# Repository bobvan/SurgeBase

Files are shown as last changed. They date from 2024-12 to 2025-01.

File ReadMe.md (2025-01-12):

# Overview
This is a simple project to make a blue LED appear to "surge" by
ramping the brightness.
It's made from a low-power MCU and an addressable
RGB LED ("NeoPixel").
The ramping code is CircuitPython.
The hardware is designed to fit inside a 50 mm OD hemisphere, forming
the base of a Marvel Crisis Protocol figure.
Demo Shell
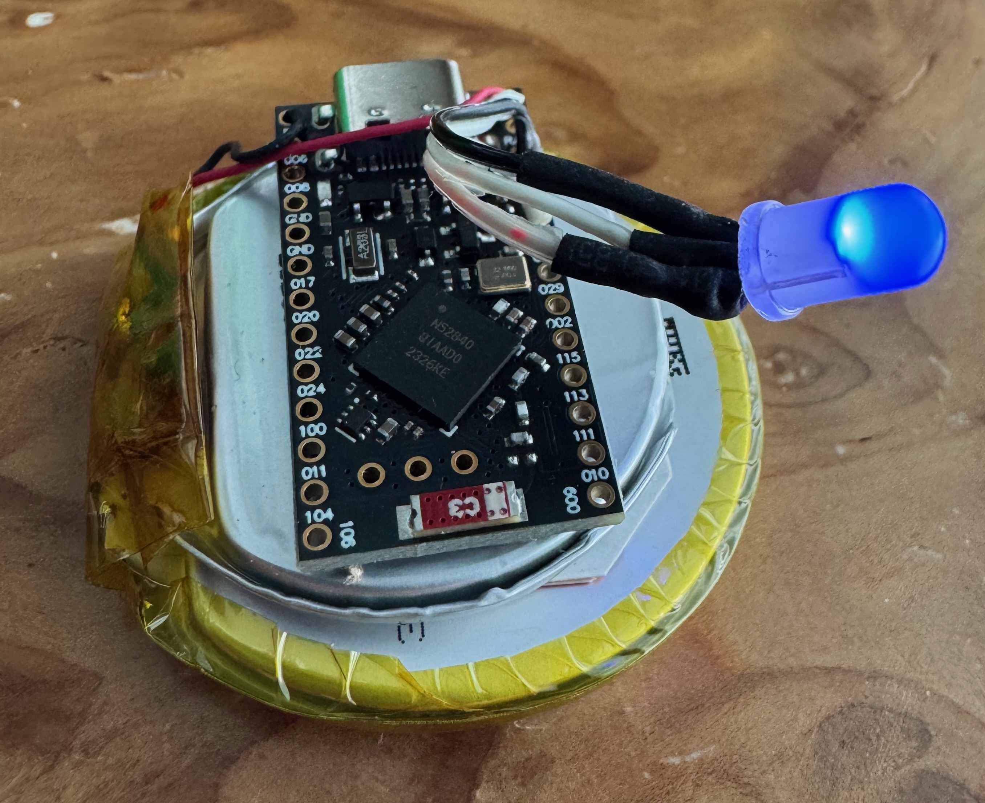
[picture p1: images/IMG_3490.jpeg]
Guts Without Shell One

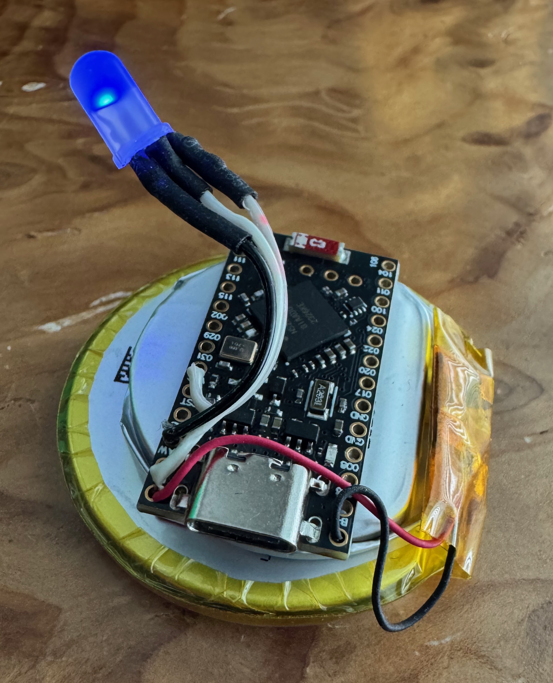
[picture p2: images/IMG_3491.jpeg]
Guts Without Shell Two


# Hardware
* NRF52840 Low Power MCU https://www.amazon.com/dp/B0DCZJKYL1
* 5 mm RGB LED with integrated controller, often called "NeoPixel" by Adafruit, or goes by part number WS2811 or WS2812: https://www.amazon.com/gp/product/B071FND4WK/
* Grepow Round LiPo Battery 1050 mAh, 45 mm: https://www.digikey.com/en/products/detail/grepow-inc/GRP604543-1C-3-85V-1050mAh/25603150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
  * This version doesn't have the protection circucit
  * It was the only one of this capacity and size when I ordered
  * I just soldered it on to the protection circuit of the cell below
* Grepow Round LiPo Battery 545 mAh, 35 mm: https://www.digikey.com/en/products/detail/grepow-inc/GRP483535-3-8V-545MAH/13681485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

# Software
* Circuit Python 9.2.1. Binary in `Downloads`.
* NeoPixel Driver Libary for above, extracted from `adafruit-circuitpython-bundle-9.x-mpy-20241224`. Binary in `Downloads`.

# Software Installation
* When you plug in the NRF52840 fresh from the factory, it will mount the MCU flash for running firmware as a volume named `NICENANO`.
* Copy the CircuitPython `.UF2` file from `Downloads` to that volume to install the firmware on the flash of the MCU.
```
cp Downloads/adafruit-circuitpython-supermini_nrf52840-en_US-9.2.1.uf2 /Volumes/NICENANO
```
* Successful installation of CircuitPython will cause the MCU to reboot, so you'll get a warning message that the `NICENANO` volume was not ejected before disconnecting. This is expected.
* When CircuitPython boots, it will mount the flash used for running CircuitPython code as a volume named `CIRCUITPY`.
* Copy the NeoPixel library from `Downloads` into the `/lib/` directory of that volume.
```
cp Downloads/neopixel.mpy /Volumes/CIRCUITPY/lib/
```
* Finally copy the SurgeBase code to the `CIRCUITPY` volume.
```
cp fw/code.py /Volumes/CIRCUITPY
```
* Eject the `CIRCUITPY` volume.
* Plug out the MCU and then plug it back in. The MCU should reboot and start running SurgeBase if you haven't attached a battery.

# Construction
* Spread four leads of LED.
* Cut off the one on the flat side. (It would daisy chain to the next LED in sequence, but we're only using one.)
* Cut the remaining three legs where they have a crimp mark.
* Prepare three stranded wires about 45 mm to connect the LED to the MCU.
* Prepare three pieces of heat shrink tubing about 8 mm.
* Strip about 5 mm of insulation.
* If PVC insulation, be ready for it to shrink back several mm when soldered.
* If ribbon cable, split LED end back so when heat shrink is placed over it, at least 5 mm of insulation is exposed.
* Place heat shrink tubing over wires.
* Tin ends.
* Solder LED to tinned wires.
* Slide tubing over solder joints and heat to shrink.
* Solder wires to MCU following table below.

| NeoPixel Pin | MCU Pin |
|---|---|
| `Data In` | `031` |
| `+5 V` | `B+` |
| `Ground` | `GND` |
| `Data Out` | N/C |
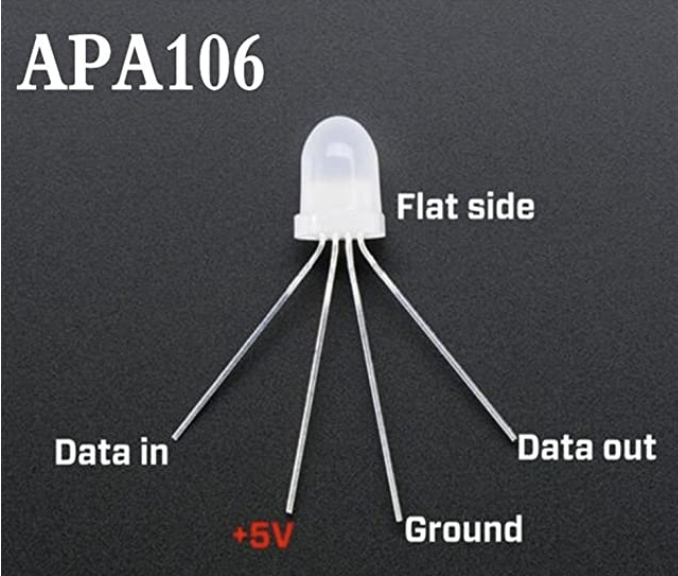
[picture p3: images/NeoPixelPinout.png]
NeoPixel Pinout

* If 1050 mAh batter doesn't have a BMS or Protection Circuit Module (PCM) but the 545 mAh battery does, then kludge them to both use the same BMS:
  * Charge both batteries fully.
  * Remove tape on BMS.
  * Tin cell tabs on both batteries.
  * Solder cells in parallel.
  * Insulate with Kapton tape.
* Solder battery to `B-` and `B+` pins of MCU.
* Use foam mounting tape to secure batteries and PCB.
* Use putty to stick assembly to shell.

# Troubleshooting
* If light blinks, MCU may by hung from power glitches while soldering the battery. Try briefly shorting the MCU `RST` pin to `GND` to reset it.
* For debugging or development, connect MCU USB to a host and run a terminal emulator on the USB serial port at 115200 baud.
```
screen /dev/cu.usbmodem11401
```
* You may have to hit `Control-C` to interrupt Circuit Python to get a REPL prompt if it's busy running your code.

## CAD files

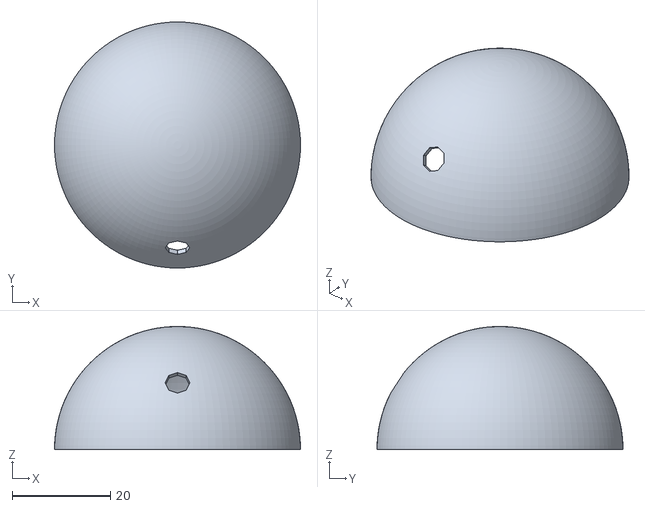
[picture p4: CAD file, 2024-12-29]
shell/shell.stl
50.0 x 50.0 x 25.0

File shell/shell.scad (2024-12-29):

// Parameters for the hemisphere
radius = 25;  // Radius of the hemisphere

module hemisphere(radius) {
    difference() {
        // Full sphere
        sphere(r = radius, $fn = 100);

        // Remove the lower half
        translate([0, 0, -radius/2])
            cube([radius * 2, radius * 2, radius], center = true);
    }
}

difference() {
    hemisphere(radius);
    hemisphere(radius-1);
    rotate([57, 0, 0]) {
         cylinder(radius*2, 2.5, 2.5);
    }
}

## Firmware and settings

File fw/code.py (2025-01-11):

# flake8: noqa: E221
#
# Ramp the brightness of a NeoPixel blue LED up and down logarithmically, resulting
# a linear ramp in perceived brightness.
# Should result in a surging effect.

import board
import neopixel
import math
import time

# Configuration Constants
rampSteps  = 40  # Number of steps as ramp rises and falls
rampStepMs = 30  # Time in milliseconds between steps
neoPin     = board.P0_31   # Pin for NeoPixel

# Manifest Constants
ledMax = 255    # Max brightness value for LED

# Derived Constants
brightStep = 1/rampSteps    # Size of steps in linear ramp

# Ten percent fudge factor to account for accumulating floating point errors
brightFudge = brightStep/10

np = neopixel.NeoPixel(neoPin, 1)

ramp = []       # Ramp of calculated brightness values

# Converting a linear brightness of 0 to a logarithmic brightness takes exp(0),
# which is 1, so the LED never goes off unless the first value is forced to 0.
ramp.append(0)

# Increasing brightness ramp
linBright = brightStep
while linBright <= 1+brightFudge:
    logBright = int(math.exp(linBright * math.log(ledMax)))
    ramp.append(logBright)
    linBright += brightStep

# Decreasing brightness ramp
linBright = 1
while linBright >= brightStep+brightFudge:
    linBright -= brightStep
    logBright = int(math.exp(linBright * math.log(ledMax)))
    ramp.append(logBright)

assert len(ramp) == 2*rampSteps, \
       "Expecting ramp length of " + str(2*rampSteps) + \
       ", got " + str(len(ramp))
print(ramp)

while True:
    for brightness in ramp:
        np[0] = (0, 0, brightness) # Set NeoPixel blue LED to calculated brightness
        np.write()
        time.sleep(rampStepMs/1000)

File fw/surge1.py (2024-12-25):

# Surging brightness effect using PWM on an individual LED.
from machine import Pin, PWM
from time import sleep
import math

# Initialize PWM on the LED pin
led_pin = Pin(2)  # Replace with your LED pin number
led_pwm = PWM(led_pin)
led_pwm.freq(1000)  # Set PWM frequency to 1kHz

# Function to calculate duty cycle based on human perception
def perceived_brightness(level, max_duty):
    """
    Maps a level (0 to 1) to a logarithmic brightness scale (0 to max_duty).
    """
    return int(math.exp(level * math.log(max_duty)))

# Parameters
min_brightness = 0  # 0% brightness
max_brightness = 1  # 100% brightness
max_duty = 1023     # Maximum duty cycle for PWM (10-bit resolution)

# Loop to cycle brightness
while True:
    # Increase brightness from min to max
    for level in range(101):  # 0 to 100
        duty = perceived_brightness(level / 100, max_duty)
        led_pwm.duty_u16(duty)  # Adjust brightness
        sleep(0.02)  # Delay to see the effect

    # Decrease brightness from max to min
    for level in range(100, -1, -1):  # 100 to 0
        duty = perceived_brightness(level / 100, max_duty)
        led_pwm.duty_u16(duty)  # Adjust brightness
        sleep(0.02)  # Delay to see the effect

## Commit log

2024-12-29 Added shell and moved firmware to fw/
    [shell.scad, shell.stl]
2025-01-11 Convert to Circuit Python
